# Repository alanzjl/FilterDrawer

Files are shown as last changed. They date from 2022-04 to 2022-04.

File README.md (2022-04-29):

# 2'' Filter Drawer for astrophotography

Designed by JZ, https://alanz.info/

This is a filter drawer that houses a single 2'' filter that you may want to use between your telescope and your camera.
I've added both a Nikon-F mount adapter and a Canon-EF mount adapter.
Both adapters are designed to give the DSLR a standard 55mm flange-to-sensor distance.

One side of the drawer connects to the camera, the otherside accepts 2'' barrel and locks with thumbscrews.

rendering

## Recommended print settings

Try to print with higher wall thickness and infill to increase structure rigidity. I use 3 wall line counts and 90% infill.
I don't think 90% is really necessary, but I did this mainly to block external lights.
You may also want to consider painting the inside for better light blocking.

I use 0.1mm layer height for the filter holder and 0.2mm for the drawer body.
The filter holder has M48 0.75 threads on it, so smaller layer height will help.

I think all rigid common filament should work (PLA, ABS, etc), by "rigid" I mean not flexibile, e.g. TPU. I printed mine with carbon fiber reinforced polycarbonate, which wasn't really necessary but I happened to have some laying around.

There is indeed one part called "TPU_locker" that you may want to print with TPU. 
It isn't really necessary, but good to have if you have TPU filament.

## Hardware

1. M3x10 screw x 4
2. M3 thumbscrew x 3 (or just use M3x8)
3. M3 nuts x7

## Other advice

Don't over screw the filter since the thread is 3d printed!

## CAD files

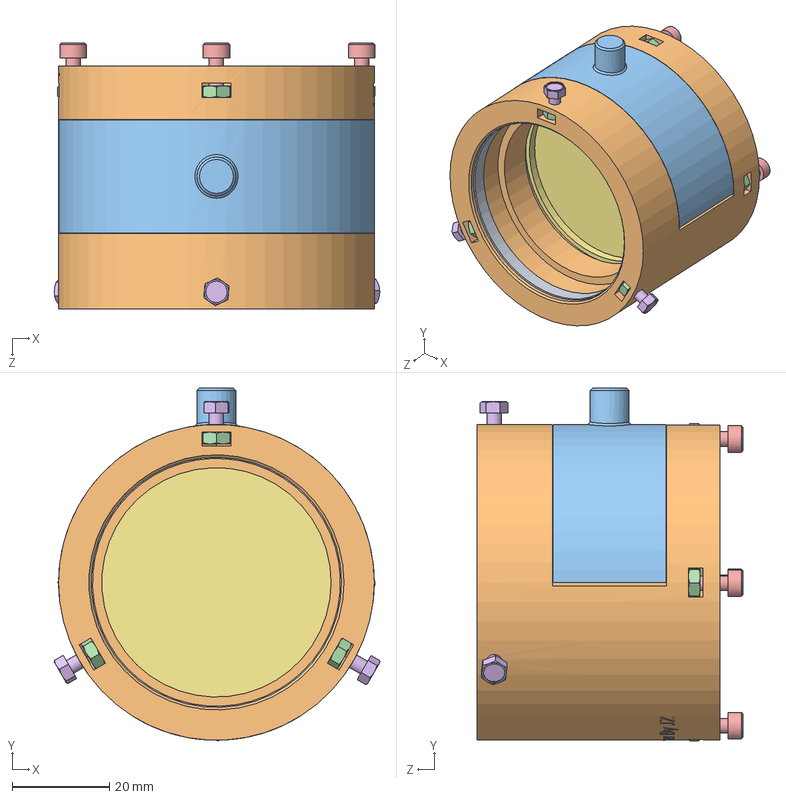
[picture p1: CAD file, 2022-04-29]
Assem1.SLDASM
67.0 x 72.7 x 54.7 mm
holder
drawer
TPU_locker
hex nut style 1_am x 7
socket head cap screw_am x 4
hex screw_am x 3
filter

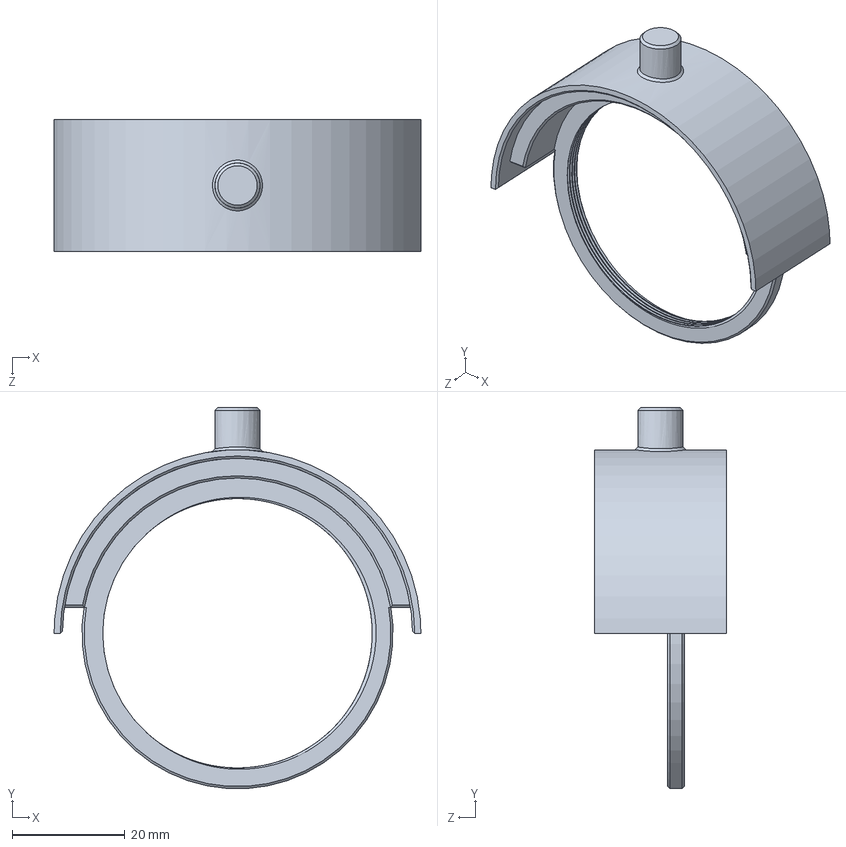
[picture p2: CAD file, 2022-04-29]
drawer.SLDPRT
65.0 x 67.5 x 23.3 mm

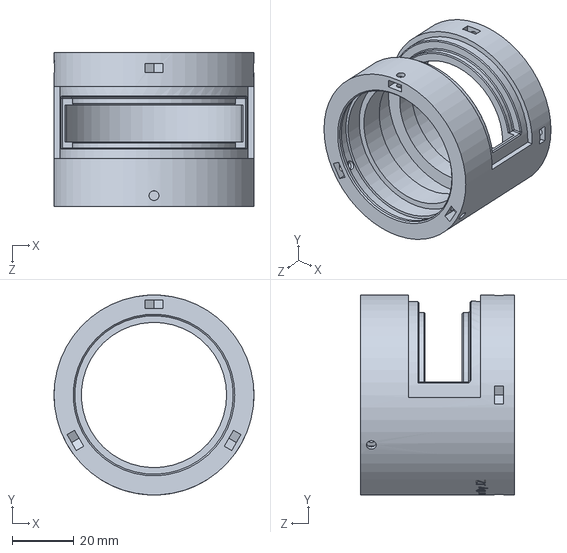
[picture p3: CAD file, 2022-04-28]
holder.SLDPRT
65.0 x 65.0 x 50.0 mm

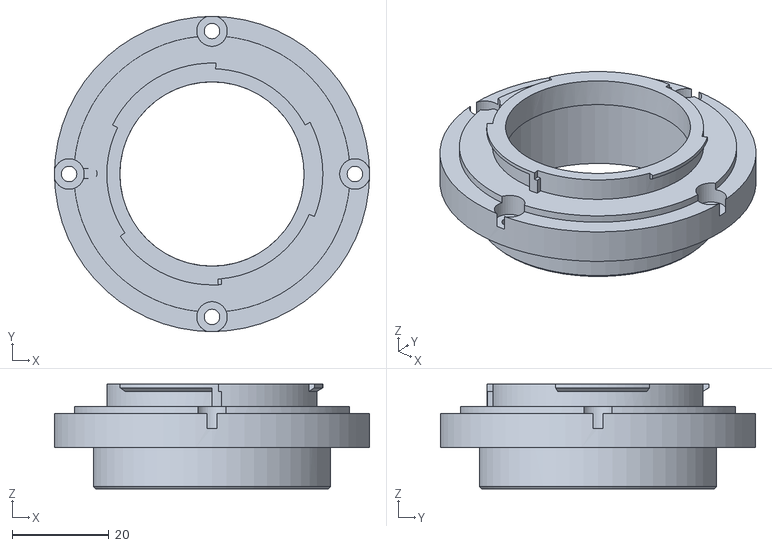
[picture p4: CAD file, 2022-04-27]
Nikon_F_mount.STL
65.0 x 65.0 x 21.6

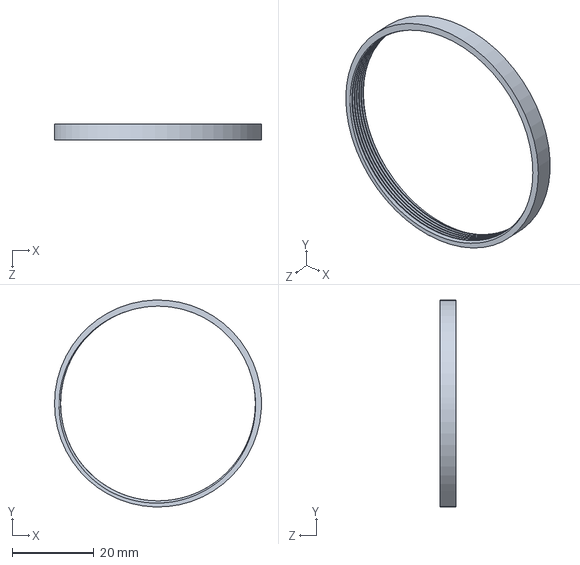
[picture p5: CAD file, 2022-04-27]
test_thread.SLDPRT
50.6 x 50.6 x 4.00 mm

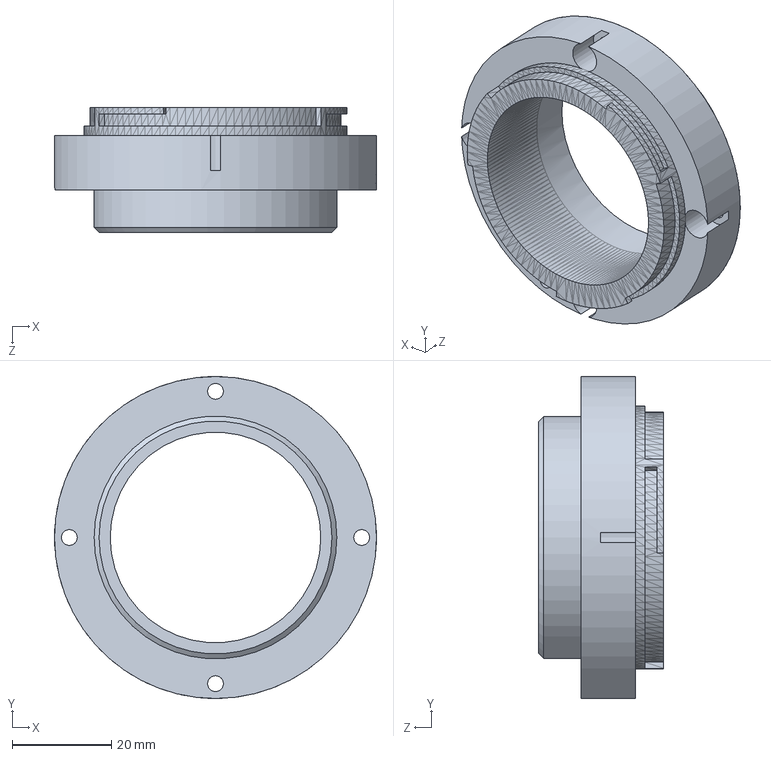
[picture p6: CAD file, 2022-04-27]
Canon_EF_mount.SLDPRT
65.0 x 65.0 x 25.2 mm

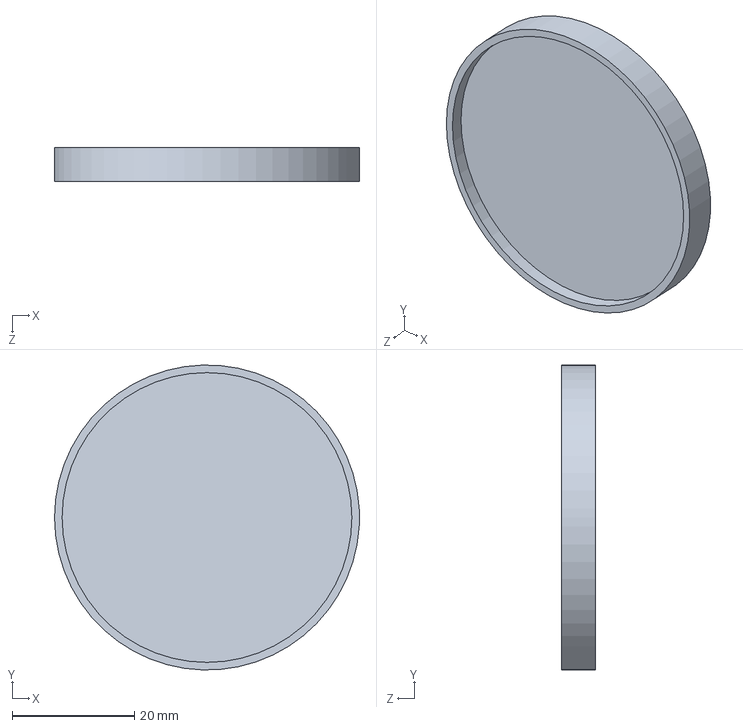
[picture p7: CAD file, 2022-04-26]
filter.SLDPRT
50.0 x 50.0 x 5.50 mm

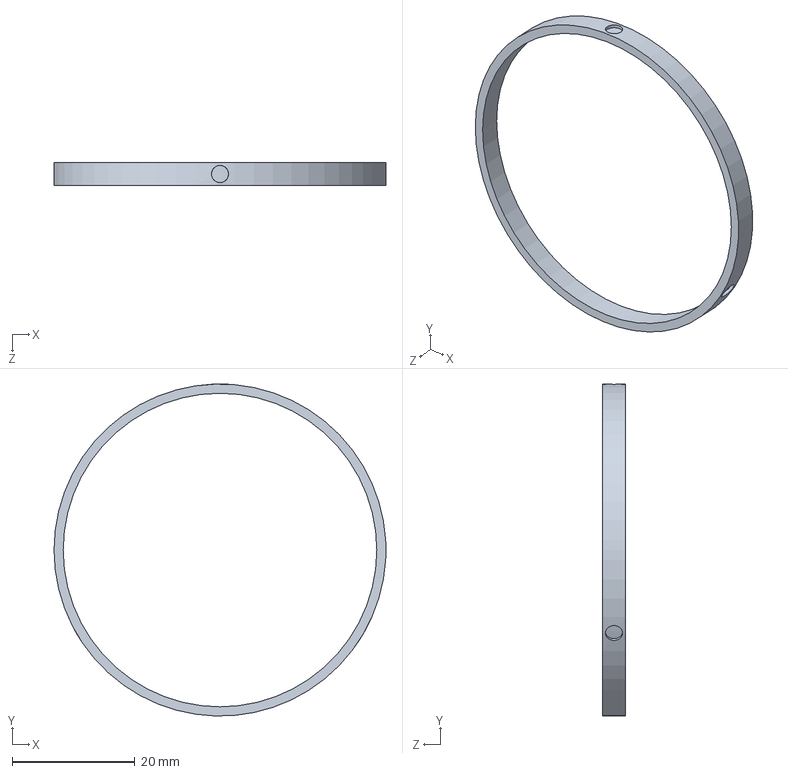
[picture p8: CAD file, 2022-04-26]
TPU_locker.SLDPRT
54.0 x 54.0 x 3.70 mm

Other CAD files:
Canon_EF_mount.STL
TPU_locker.STL
drawer.STL
holder.STL
test_thread.STL

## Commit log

2022-04-27 add readme and ef mount
    [Assem1.SLDASM, Canon_EF_mount.SLDPRT, Canon_EF_mount.STL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]
2022-04-28 loosen the thread just a little bit
    [Assem1.SLDASM, drawer.SLDPRT, drawer.STL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]
2022-04-29 more snug fit between drawer and body
    [Assem1.SLDASM, drawer.SLDPRT, drawer.STL]
2022-04-29 update BOM
